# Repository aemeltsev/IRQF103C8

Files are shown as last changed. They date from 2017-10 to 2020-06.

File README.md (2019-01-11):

License
-------

IRQF103C8 schematic files and documentations are distributed under 
Creative Commons Attribution 4.0 International License.

Overview
--------
Using STM32 microcontroller for rapid prototyping.

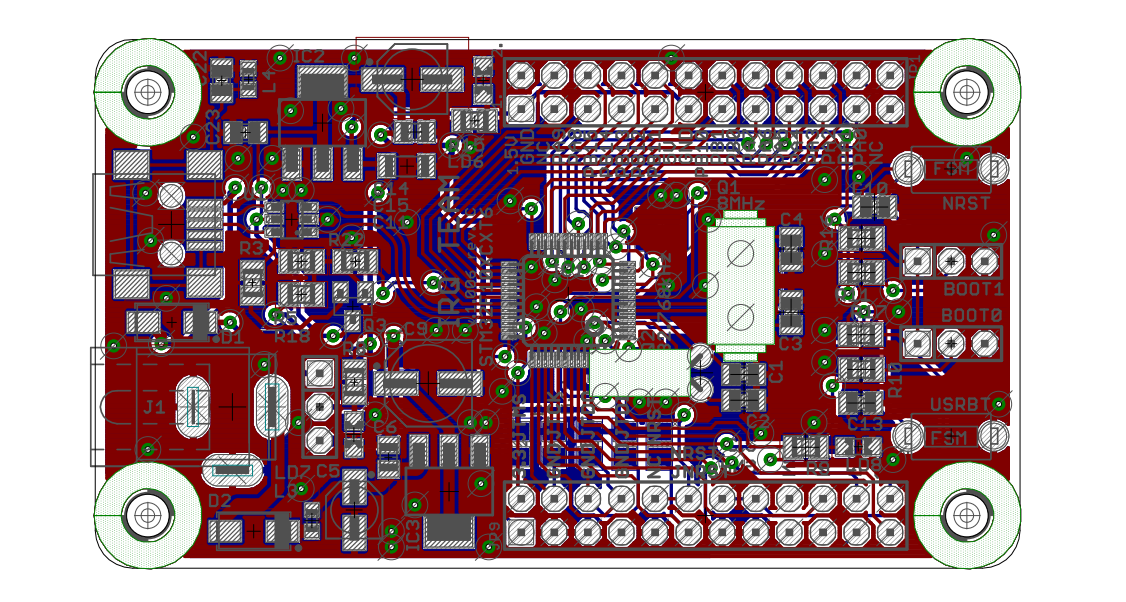
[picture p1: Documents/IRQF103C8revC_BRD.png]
PCB image


[IRQF103C8revC_BRD]: https://github.com/aemeltsev/IRQF103C8/blob/master/Documents/IRQF103C8revC_BRD.png

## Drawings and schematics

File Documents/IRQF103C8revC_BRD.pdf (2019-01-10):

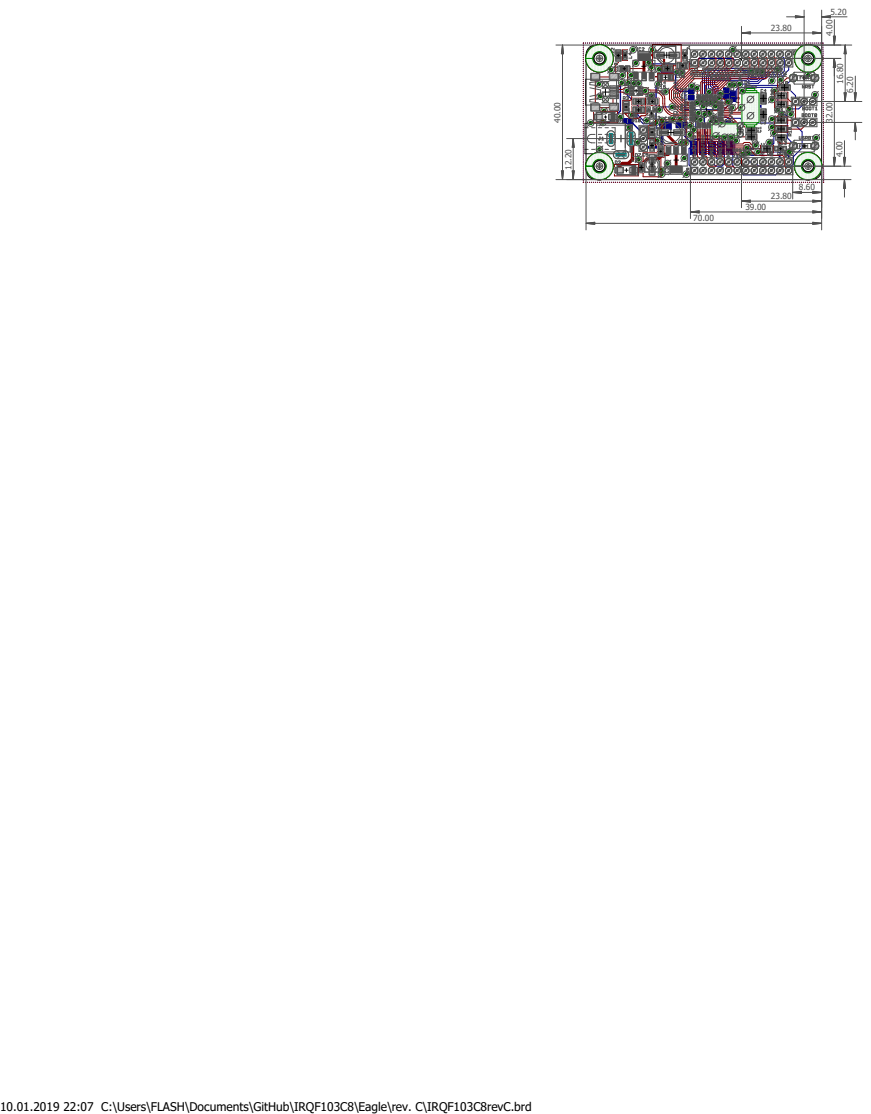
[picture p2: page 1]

10.01.2019 22:07 C:\Users\FLASH\Documents\GitHub\IRQF103C8\Eagle\rev. C\IRQF103C8revC.brd

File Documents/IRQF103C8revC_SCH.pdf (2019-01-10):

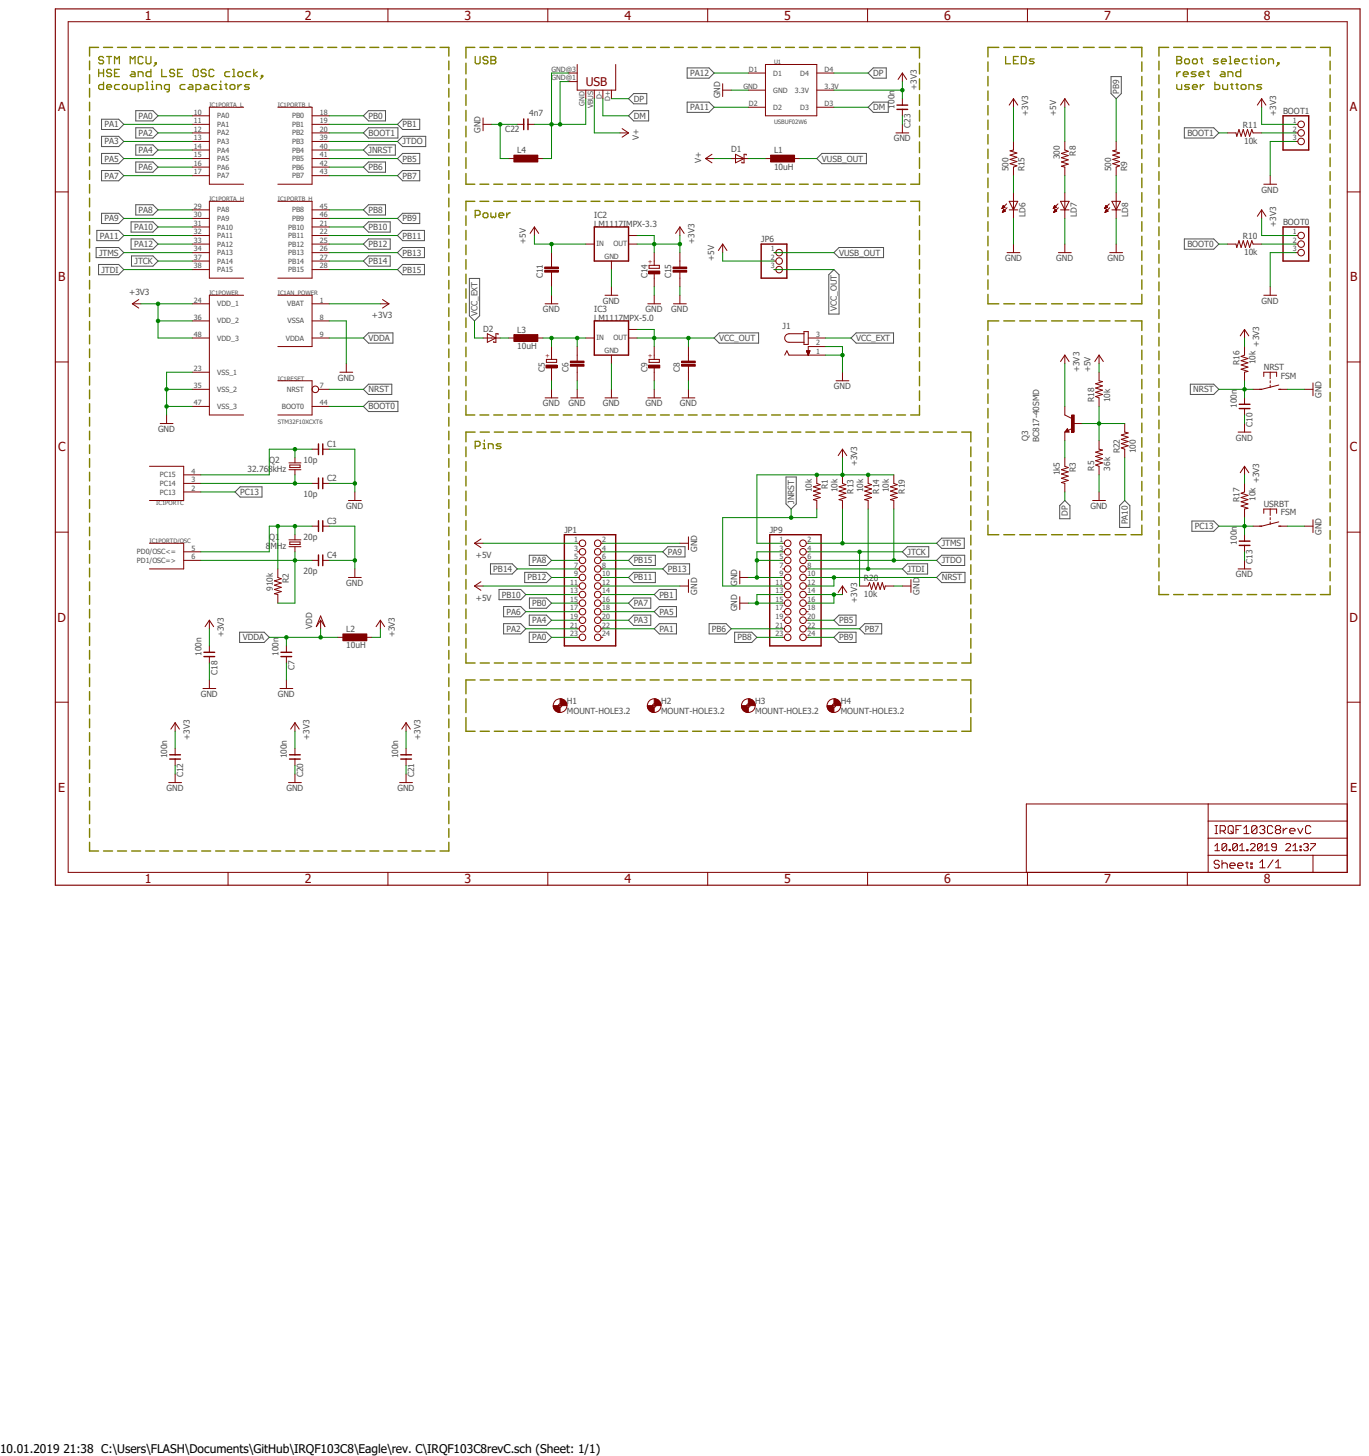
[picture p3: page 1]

10.01.2019 21:38 C:\Users\FLASH\Documents\GitHub\IRQF103C8\Eagle\rev. C\IRQF103C8revC.sch (Sheet: 1/1)

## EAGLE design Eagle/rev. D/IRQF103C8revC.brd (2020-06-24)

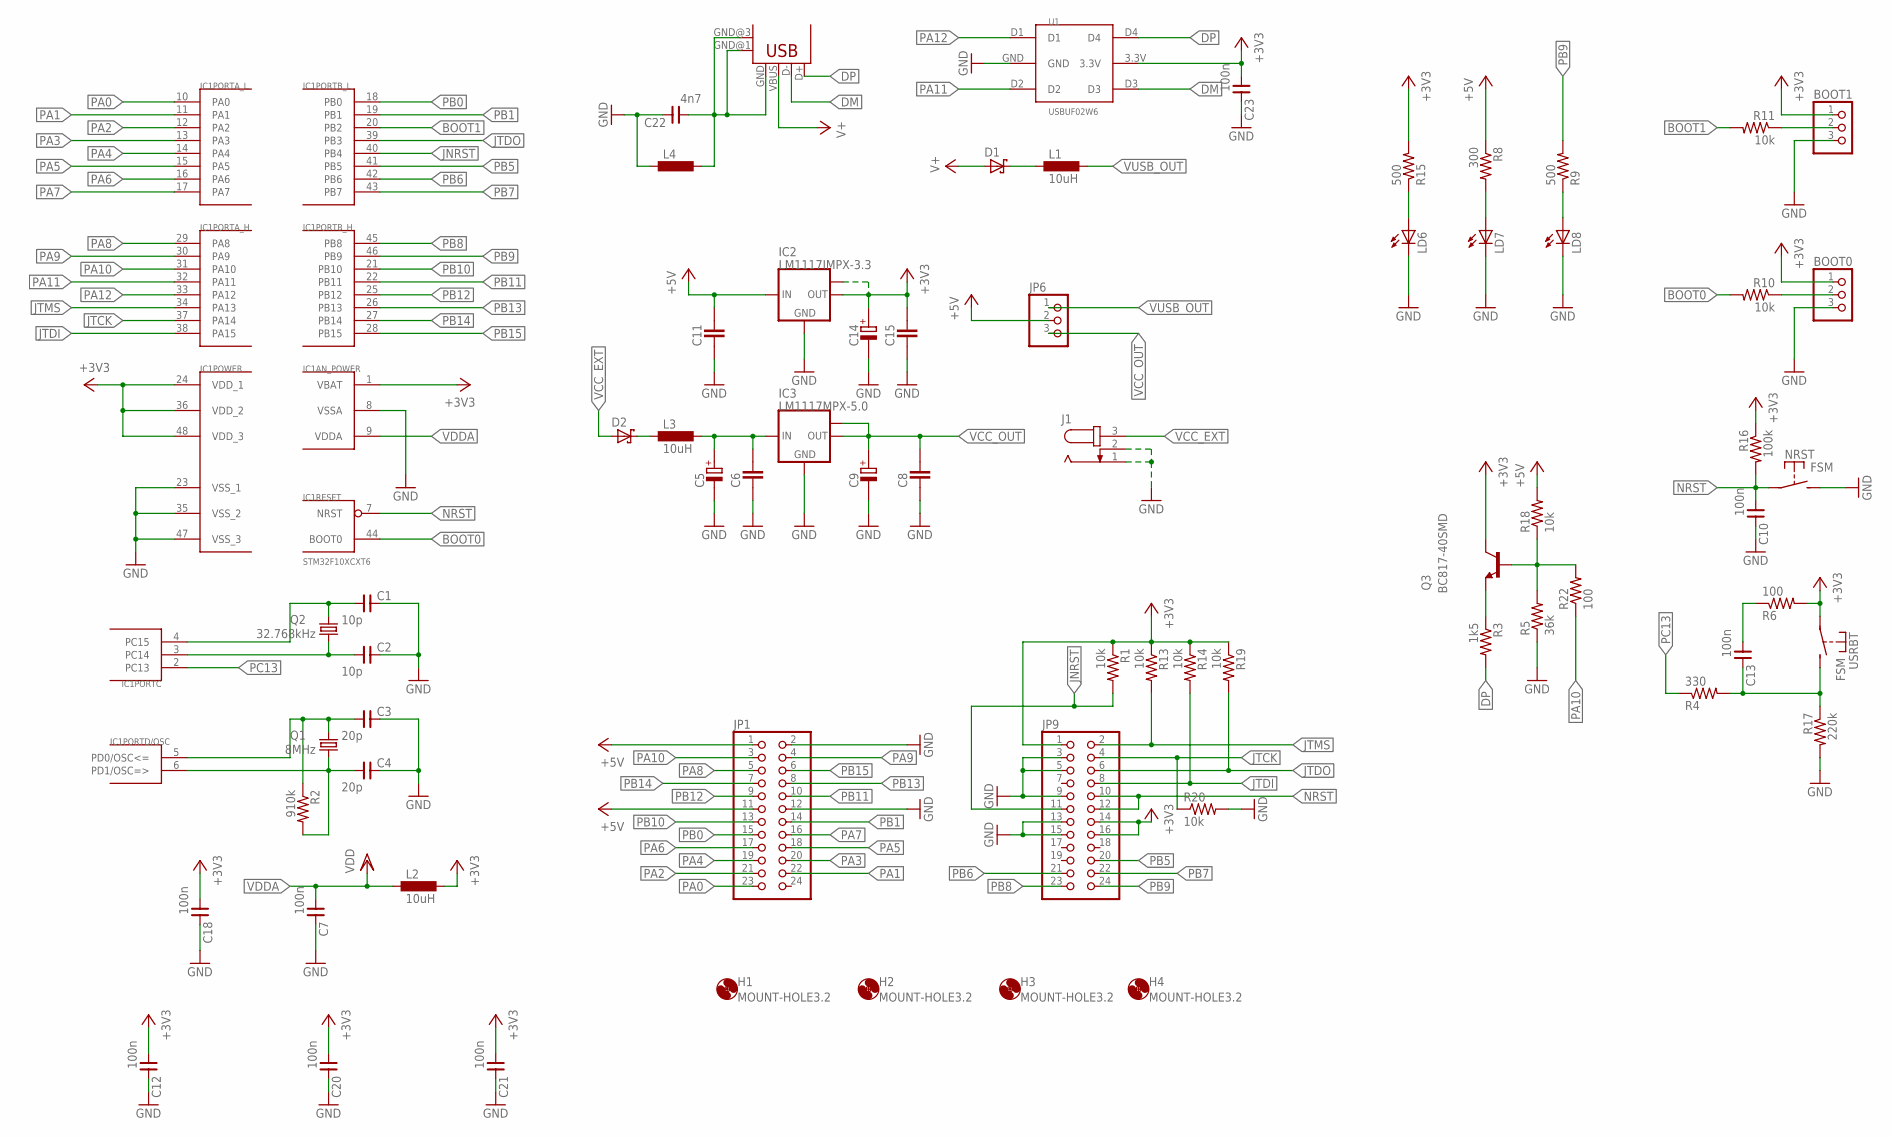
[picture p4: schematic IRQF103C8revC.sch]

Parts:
BOOT0, BOOT1: PINHD-1X3; 1X03
C1, C2: 10p; 0805
C3, C4: 20p; 0805
C5: POLARISED_CASE_B; CAPAE430X540N
C6, C8, C15: CAPACITOR_0805; CAPC2012X145AN
C7, C10, C12, C13, C18, C20, C21, C23: 100n; 0805
C9: POLARISED_CASE_D; CAPAE660X540N
C11: CAPACITOR_1206; CAPC3215X168N
C14: POLARISED_CASE_C; CAPAE530X540N
C22: 4n7; 0805
D1, D2: SCHOTTKY_SMA; DIOM5326X292N
H1, H2, H3, H4: MOUNT-HOLE3.2; 3,2
IC1: STM32F10XCXT6; TQFP48
IC2: LM1117IMPX-3.3; SOT223
IC3: LM1117MPX-5.0; SOT223
J1: JACK-PLUG1; SPC4078
JP1, JP9: PINHD-2X12; 2X12
JP6: PINHD-1X3; 1X03
L1, L2, L3: 10uH; INDC1608X95N
L4: INDUCTOR_0603; INDC1608X95N
LD6, LD7, LD8: LEDCHIPLED_0805; CHIPLED_0805
NRST: FSM
Q1: 8MHz; HC49/S
Q2: 32.768kHz; TC26H
Q3: BC817-40SMD; SOT23-BEC
R1, R10, R11, R13, R14, R18, R19, R20: 10k; M0805
R2: 910k; M0805
R3: 1k5; M0805
R4: 330; M0805
R5: 36k; M0805
R6, R22: 100; M0805
R8: 300; M0805
R9, R15: 500; M0805
R16: 100k; M0805
R17: 220k; M0805
U1: USBUF02W6; SOT23-6L
USB1: USB-MB-S
USRBT: FSM

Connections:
+3V3: BOOT0.1, BOOT1.1, C12.1, C14.+, C15.2, C18.1, C20.1, C21.1, C23.1, IC1.1 (VBAT), IC1.24 (VDD_1), IC1.36 (VDD_2), IC1.48 (VDD_3), IC2.2 (OUT), IC2.TAB (OUT1), JP9.1, JP9.14, JP9.16, L2.2, Q3.C, R1.1, R6.2, R13.1, R14.1, R15.2, R16.1, R19.1, U1.3.3V, USRBT.P$1
+5V: C11.2, IC2.3 (IN), JP1.1, JP1.11, JP6.2, R8.1, R18.2
BOOT0: IC1.44 (BOOT0), R10.2
BOOT1: IC1.20 (PB2), R11.2
DM: U1.D3, USB1.D-
DP: R3.2, U1.D4, USB1.D+
GND: BOOT0.3, BOOT1.3, C1.2, C2.2, C3.2, C4.2, C5.-, C6.1, C7.2, C8.1, C9.-, C10.2, C11.1, C12.2, C14.-, C15.1, C18.2, C20.2, C21.2, C22.2, C23.2, IC1.8 (VSSA), IC1.23 (VSS_1), IC1.35 (VSS_2), IC1.47 (VSS_3), IC2.1 (GND), IC3.1 (GND), J1.1, J1.2, JP1.2, JP1.12, JP9.3, JP9.5, JP9.9, JP9.13, JP9.15, L4.1, LD6.C, LD7.C, LD8.C, NRST.P$2 (S), R5.1, R17.2, R20.2, U1.GND
JNRST: IC1.40 (PB4), JP9.11, R1.2
JTCK: IC1.37 (PA14), JP9.4, R20.1
JTDI: IC1.38 (PA15), JP9.8, R14.2
JTDO: IC1.39 (PB3), JP9.6, R19.2
JTMS: IC1.34 (PA13), JP9.2, R13.2
unnamed: C2.1, IC1.3 (PC14), Q2.1
unnamed: C1.1, IC1.4 (PC15), Q2.2
unnamed: C4.1, IC1.6 (PD1/OSC=>), Q1.1, R2.2
unnamed: C3.1, IC1.5 (PD0/OSC<=), Q1.2, R2.1
unnamed: BOOT0.2, R10.1
unnamed: LD7.A, R8.2
unnamed: D2.K, L3.1
unnamed: D1.K, L1.1
unnamed: Q3.B, R5.2, R18.1, R22.2
unnamed: C5.+, C6.2, IC3.3 (IN), L3.2
unnamed: Q3.E, R3.1
unnamed: C13.2, R4.2, R17.1, USRBT.P$2 (S)
unnamed: C13.1, R6.1
unnamed: LD8.A, R9.1
unnamed: C22.1, L4.2, USB1.GND, USB1.GND@1 (GND), USB1.GND@3 (GND)
unnamed: LD6.A, R15.1
NRST: C10.1, IC1.7 (NRST), JP9.10, JP9.12, NRST.P$1, R16.2
PA0: IC1.10 (PA0), JP1.23
PA1: IC1.11 (PA1), JP1.22
PA2: IC1.12 (PA2), JP1.21
PA3: IC1.13 (PA3), JP1.20
PA4: IC1.14 (PA4), JP1.19
PA5: IC1.15 (PA5), JP1.18
PA6: IC1.16 (PA6), JP1.17
PA7: IC1.17 (PA7), JP1.16
PA8: IC1.29 (PA8), JP1.5
PA9: IC1.30 (PA9), JP1.4
PA10: IC1.31 (PA10), JP1.3, R22.1
PA11: IC1.32 (PA11), U1.D2
PA12: IC1.33 (PA12), U1.D1
PB0: IC1.18 (PB0), JP1.15
PB1: IC1.19 (PB1), JP1.14
PB2: BOOT1.2, R11.1
PB5: IC1.41 (PB5), JP9.20
PB6: IC1.42 (PB6), JP9.21
PB7: IC1.43 (PB7), JP9.22
PB8: IC1.45 (PB8), JP9.23
PB9: IC1.46 (PB9), JP9.24, R9.2
PB10: IC1.21 (PB10), JP1.13
PB11: IC1.22 (PB11), JP1.10
PB12: IC1.25 (PB12), JP1.9
PB13: IC1.26 (PB13), JP1.8
PB14: IC1.27 (PB14), JP1.7
PB15: IC1.28 (PB15), JP1.6
PC13: IC1.2 (PC13), R4.1
V+: D1.A, USB1.VBUS
VCC_EXT: D2.A, J1.3
VCC_OUT: C8.2, C9.+, IC3.2 (OUT), IC3.TAB (OUT1), JP6.3
VDDA: C7.1, IC1.9 (VDDA), L2.1
VUSB_OUT: JP6.1, L1.2

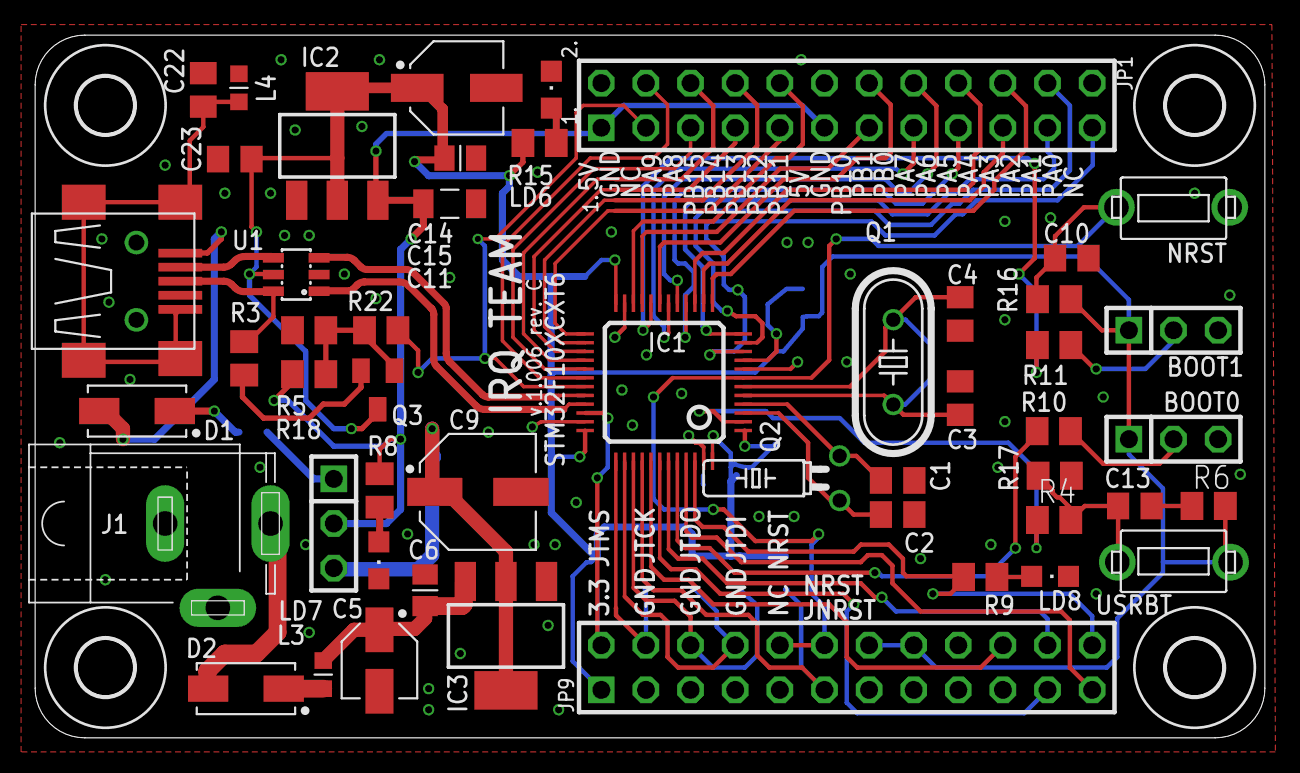
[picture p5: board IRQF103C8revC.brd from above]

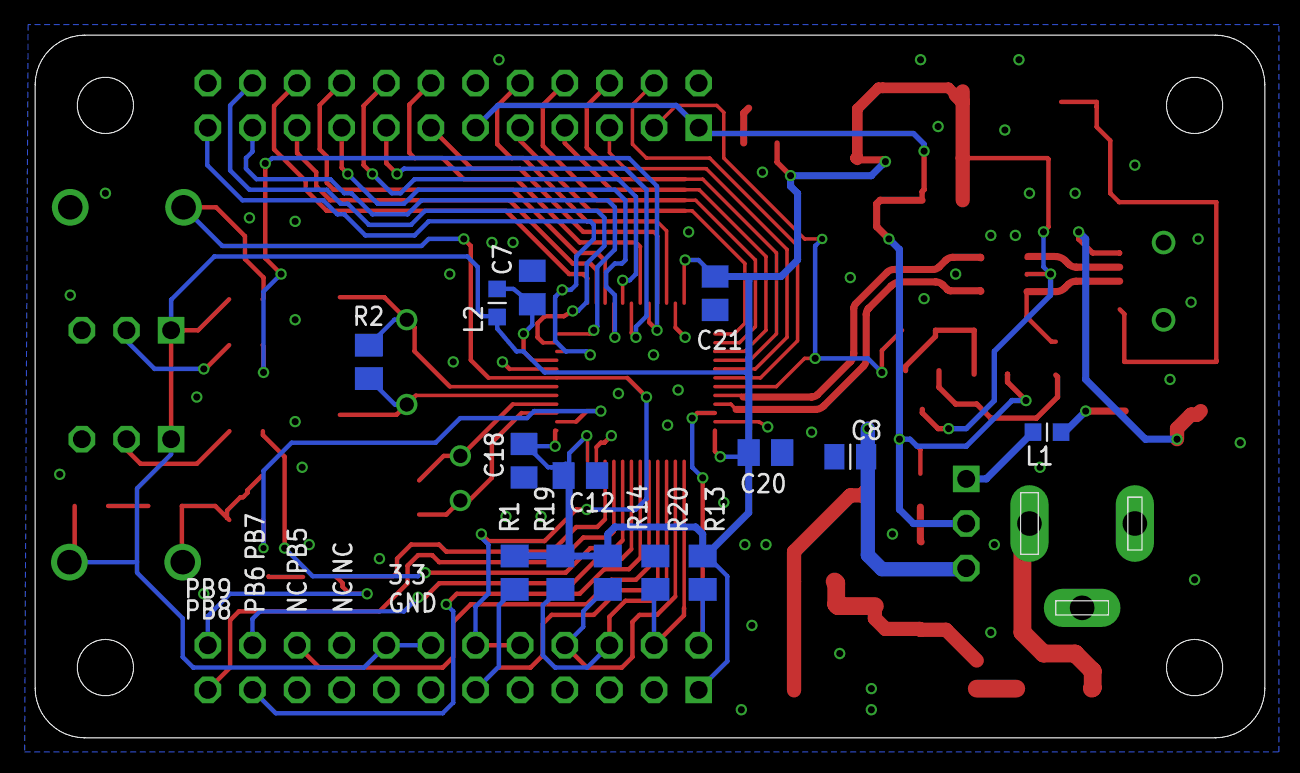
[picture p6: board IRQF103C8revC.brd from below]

Board: 2 copper layers, 70.0 x 40.0 mm, 68 parts (14 on the bottom side), 62 nets.

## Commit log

2017-10-15 Add Files
    Add Files
    [IRQF103C8.brd, IRQF103C8.sch]
2017-10-16 Add doc dir
    Directory for documents
    [IRQF103C8.sch]
2017-10-18 Update files
    Update schematic & pcb files
    [IRQF103C8.brd, IRQF103C8.sch]
2017-10-26 rev. A
    add revision folder
    [IRQF103C8.brd, IRQF103C8.sch]
2017-10-27 refresh
    Refresh and update files
    [IRQF103C8revA.brd, IRQF103C8revA.sch, IRQF103C8revB.brd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]
2019-01-10 Rev.C
    Add rev. C, and SCH BRD pdf file
    [IRQF103C8revC.brd, IRQF103C8revC.sch]
2020-03-10 rev
    New revision
    [IRQF103C8revC.brd, IRQF103C8revC.sch]
2020-06-24 update circuit
    Connect GPIOA 10 to NC pin, using pwm
    [IRQF103C8revC.brd, IRQF103C8revC.sch]

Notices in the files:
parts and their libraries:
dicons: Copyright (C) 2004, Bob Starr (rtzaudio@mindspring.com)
